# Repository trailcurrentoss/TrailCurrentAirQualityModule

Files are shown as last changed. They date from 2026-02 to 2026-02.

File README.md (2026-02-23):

# TrailCurrent Air Quality Module

Air quality sensor module for monitoring environmental conditions including temperature, humidity, and air quality metrics. Part of the [TrailCurrent](https://trailcurrent.com) open-source vehicle platform.

## Hardware Overview

- **Function:** Environmental monitoring module combining temperature, humidity, and air quality sensing
- **Key Features:**
  - DHT22 temperature and humidity sensor
  - Air quality sensing capability
  - Compact design suitable for integration into larger systems
  - PlatformIO-based firmware for configuration and operation

## Hardware Requirements

### Components

- **Sensors:**
  - DHT22 temperature/humidity sensor
  - Air quality sensor module

- **Connectors:**
  - JST XH 4-pin connectors for power and signal distribution

### KiCAD Library Dependencies

This project uses the consolidated [TrailCurrentKiCADLibraries](https://github.com/trailcurrentoss/TrailCurrentKiCADLibraries).

**Setup:**

```bash
# Clone the library
git clone git@github.com:trailcurrentoss/TrailCurrentKiCADLibraries.git

# Set environment variables (add to ~/.bashrc or ~/.zshrc)
export TRAILCURRENT_SYMBOL_DIR="/path/to/TrailCurrentKiCADLibraries/symbols"
export TRAILCURRENT_FOOTPRINT_DIR="/path/to/TrailCurrentKiCADLibraries/footprints"
export TRAILCURRENT_3DMODEL_DIR="/path/to/TrailCurrentKiCADLibraries/3d_models"
```

See [KICAD_ENVIRONMENT_SETUP.md](https://github.com/trailcurrentoss/TrailCurrentKiCADLibraries/blob/main/KICAD_ENVIRONMENT_SETUP.md) in the library repository for detailed setup instructions.

## Opening the Project

1. **Set up environment variables** (see Library Dependencies above)
2. **Open KiCAD:**
   ```bash
   kicad /path/to/EDA/TrailCurrentAirQualityModule/TrailCurrentAirQualityModule.kicad_pro
   ```
3. **Verify libraries load** - All symbol and footprint libraries should resolve without errors
4. **View 3D models** - Open PCB and press `Alt+3` to view the 3D visualization
   - All 3D models should load from the consolidated library path
   - Models use relative `${TRAILCURRENT_3DMODEL_DIR}` references

## Firmware

See `src/` directory for PlatformIO-based firmware.

**Setup:**
```bash
# Install PlatformIO (if not already installed)
pip install platformio

# Build firmware
pio run -d /path/to/project

# Upload to board
pio run -t upload -d /path/to/project
```

### Firmware Dependencies

This firmware depends on the following public libraries:

- **[C6SuperMiniRgbLedLibrary](https://github.com/trailcurrentoss/C6SuperMiniRgbLedLibrary)** (v0.0.1) - RGB LED status indicator driver
- **[Esp32C6OtaUpdateLibrary](https://github.com/trailcurrentoss/Esp32C6OtaUpdateLibrary)** (v0.0.1) - Over-the-air firmware update functionality
- **[Esp32C6TwaiTaskBasedLibrary](https://github.com/trailcurrentoss/Esp32C6TwaiTaskBasedLibrary)** (v0.0.3) - CAN bus communication interface
- **[Adafruit DHT sensor library](https://github.com/adafruit/DHT-sensor-library)** (v1.4.6+) - Temperature and humidity sensor

All dependencies are automatically resolved by PlatformIO during the build process.

**WiFi Credentials:**
- Firmware receives WiFi credentials via CAN Bus (ID 0x01) from the TrailCurrent system
- For standalone development/testing without the TrailCurrent system, create a `secrets.h` file in `src/`:
  ```cpp
  // Copy to src/secrets.h for local development only
  // NEVER commit this file - it's in .gitignore
  const char* ssid = "YOUR_SSID_HERE";
  const char* password = "YOUR_PASSWORD_HERE";
  ```

**Future Enhancement:** WiFi credential configuration will be fully implemented via CAN Bus protocol, allowing credentials to be distributed from the TrailCurrent system without firmware modifications.

## Manufacturing

- **PCB Files:** Ready for fabrication via standard PCB services (JLCPCB, OSH Park, etc.)
- **BOM Generation:** Export BOM from KiCAD schematic (Tools → Generate BOM)
- **JLCPCB Assembly:** This project supports automated assembly using JLCPCB
  - See [BOM_ASSEMBLY_WORKFLOW.md](https://github.com/trailcurrentoss/TrailCurrentKiCADLibraries/blob/main/BOM_ASSEMBLY_WORKFLOW.md) for detailed assembly workflow
  - Component library includes LCSC, Mouser, and DigiKey part numbers for flexible sourcing

## Documentation

- **Schematic:** EDA/TrailCurrentAirQualityModule/TrailCurrentAirQualityModule.kicad_sch
- **PCB Layout:** EDA/TrailCurrentAirQualityModule/TrailCurrentAirQualityModule.kicad_pcb

## License

MIT License - See LICENSE file for details

This is open source hardware. You are free to use, modify, and distribute these designs for personal or commercial purposes.

## Contributing

Improvements and contributions are welcome! Please submit issues or pull requests to the main repository.

## Support

For questions about:
- **KiCAD setup:** See [KICAD_ENVIRONMENT_SETUP.md](https://github.com/trailcurrentoss/TrailCurrentKiCADLibraries/blob/main/KICAD_ENVIRONMENT_SETUP.md)
- **Library consolidation:** See [CONNECTOR_CONSOLIDATION_SUMMARY.md](https://github.com/trailcurrentoss/TrailCurrentKiCADLibraries/blob/main/CONNECTOR_CONSOLIDATION_SUMMARY.md)
- **Assembly workflow:** See [BOM_ASSEMBLY_WORKFLOW.md](https://github.com/trailcurrentoss/TrailCurrentKiCADLibraries/blob/main/BOM_ASSEMBLY_WORKFLOW.md)

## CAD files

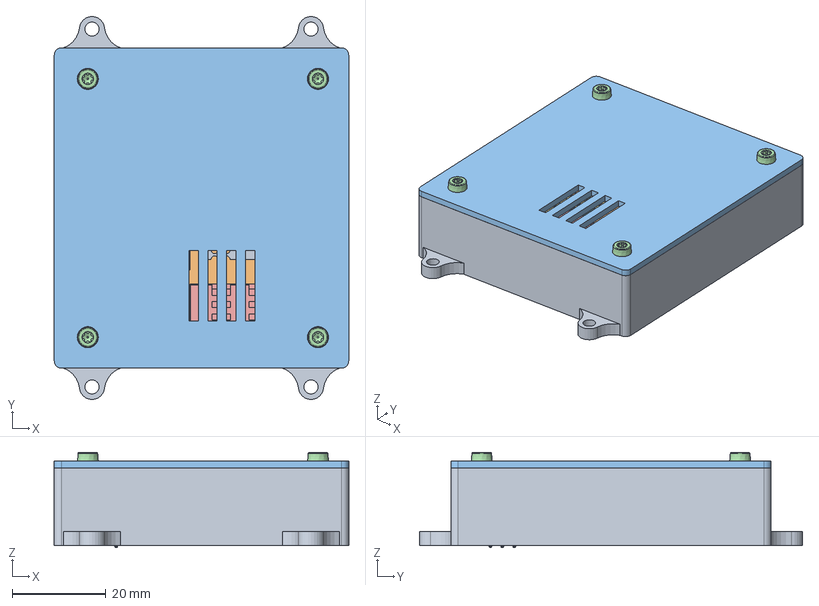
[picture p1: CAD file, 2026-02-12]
CAD/TrailCurrentAirQualityModule.FCStd
62.7 x 81.5 x 20.3 mm
BodyCaseBack
Right angle 3 pin header v1
Right angle 3 pin header v001
Right angle 3 pin header v002
dht22
PCB
USB_C_Receptacle_16P_TopMnt_Horizontal_GCT_USB4105-xx-A037
USB_C_Receptacle_16P_TopMnt_Horizontal_GCT_USB4105-xx-A038
USB_C_Receptacle_16P_TopMnt_Horizontal_GCT_USB4105-xx-A039
USB_C_Receptacle_16P_TopMnt_Horizontal_GCT_USB4105-xx-A040
USB_C_Receptacle_16P_TopMnt_Horizontal_GCT_USB4105-xx-A041
USB_C_Receptacle_16P_TopMnt_Horizontal_GCT_USB4105-xx-A042
USB_C_Receptacle_16P_TopMnt_Horizontal_GCT_USB4105-xx-A043
USB_C_Receptacle_16P_TopMnt_Horizontal_GCT_USB4105-xx-A044
USB_C_Receptacle_16P_TopMnt_Horizontal_GCT_USB4105-xx-A045
USB_C_Receptacle_16P_TopMnt_Horizontal_GCT_USB4105-xx-A046
USB_C_Receptacle_16P_TopMnt_Horizontal_GCT_USB4105-xx-A047
USB_C_Receptacle_16P_TopMnt_Horizontal_GCT_USB4105-xx-A048
USB_C_Receptacle_16P_TopMnt_Horizontal_GCT_USB4105-xx-A049
USB_C_Receptacle_16P_TopMnt_Horizontal_GCT_USB4105-xx-A050
USB_C_Receptacle_16P_TopMnt_Horizontal_GCT_USB4105-xx-A051
USB_C_Receptacle_16P_TopMnt_Horizontal_GCT_USB4105-xx-A052
USB_C_Receptacle_16P_TopMnt_Horizontal_GCT_USB4105-xx-A053
USB_C_Receptacle_16P_TopMnt_Horizontal_GCT_USB4105-xx-A054
USB_C_Receptacle_16P_TopMnt_Horizontal_GCT_USB4105-xx-A055
USB_C_Receptacle_16P_TopMnt_Horizontal_GCT_USB4105-xx-A056
USB_C_Receptacle_16P_TopMnt_Horizontal_GCT_USB4105-xx-A057
USB_C_Receptacle_16P_TopMnt_Horizontal_GCT_USB4105-xx-A058
USB_C_Receptacle_16P_TopMnt_Horizontal_GCT_USB4105-xx-A059
USB_C_Receptacle_16P_TopMnt_Horizontal_GCT_USB4105-xx-A060
USB_C_Receptacle_16P_TopMnt_Horizontal_GCT_USB4105-xx-A061
USB_C_Receptacle_16P_TopMnt_Horizontal_GCT_USB4105-xx-A062
USB_C_Receptacle_16P_TopMnt_Horizontal_GCT_USB4105-xx-A063
USB_C_Receptacle_16P_TopMnt_Horizontal_GCT_USB4105-xx-A064
USB_C_Receptacle_16P_TopMnt_Horizontal_GCT_USB4105-xx-A065
USB_C_Receptacle_16P_TopMnt_Horizontal_GCT_USB4105-xx-A066
USB_C_Receptacle_16P_TopMnt_Horizontal_GCT_USB4105-xx-A067
USB_C_Receptacle_16P_TopMnt_Horizontal_GCT_USB4105-xx-A068
USB_C_Receptacle_16P_TopMnt_Horizontal_GCT_USB4105-xx-A069
USB_C_Receptacle_16P_TopMnt_Horizontal_GCT_USB4105-xx-A070
USB_C_Receptacle_16P_TopMnt_Horizontal_GCT_USB4105-xx-A071
USB_C_Receptacle_16P_TopMnt_Horizontal_GCT_USB4105-xx-A072
Button_black_002
Button_black_003
io23
io21
io22
io12
io13
Corps
Corps001
Corps002
Corps003
Corps004
Corps005
Corps006
Corps007
Corps008
Corps009
Corps010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

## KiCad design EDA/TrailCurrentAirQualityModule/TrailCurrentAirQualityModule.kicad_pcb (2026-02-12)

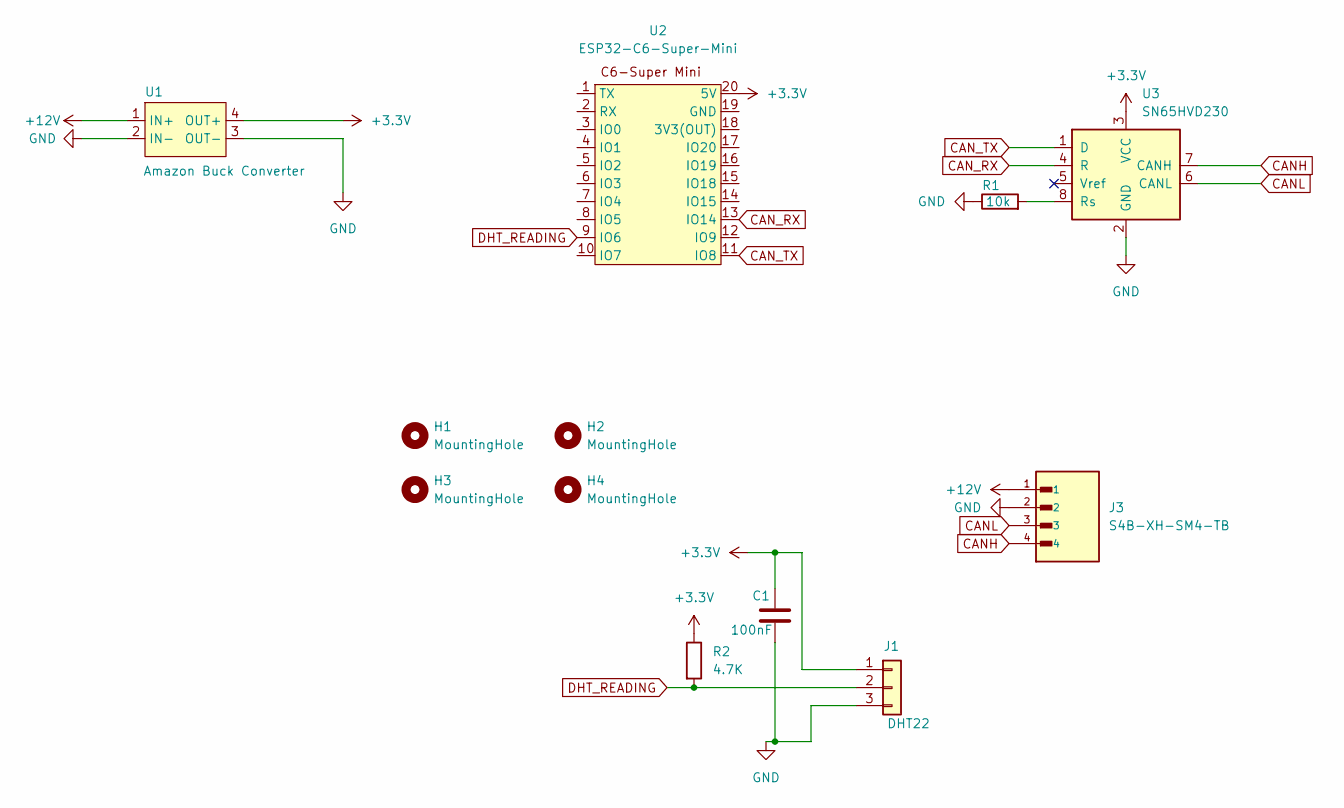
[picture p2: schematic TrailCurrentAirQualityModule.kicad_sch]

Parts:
C1: 100nF; C_1206_3216Metric_Pad1.33x1.80mm_HandSolder
H1, H2, H3, H4: MountingHole; MountingHole_2.5mm
J1: DHT22; DHT22_Module
J3: S4B-XH-SM4-TB; JST_S4B-XH-SM4-TB; PARTREV NA; LCSC C161861
R1: 10k; R_1206_3216Metric_Pad1.30x1.75mm_HandSolder
R2: 4.7K; C_1206_3216Metric_Pad1.33x1.80mm_HandSolder
U1: Amazon Buck Converter; AmazonBuckConverter
U2: ESP32-C6-Super-Mini
U3: SN65HVD230; SOIC-8_3.9x4.9mm_P1.27mm

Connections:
+3.3V: C1.1, J1.1, R2.1, U1.4 (OUT+), U2.20 (5V), U3.3 (VCC)
+12V: J3.1, U1.1 (IN+)
CANH: J3.4, U3.7 (CANH)
CANL: J3.3, U3.6 (CANL)
CAN_RX: U2.13 (IO14), U3.4 (R)
CAN_TX: U2.11 (IO8), U3.1 (D)
DHT_READING: J1.2, R2.2, U2.9 (IO6)
GND: C1.2, J1.3, J3.2, R1.1, U1.2 (IN-), U1.3 (OUT-), U3.2 (GND)
unnamed: R1.2, U3.8 (Rs)

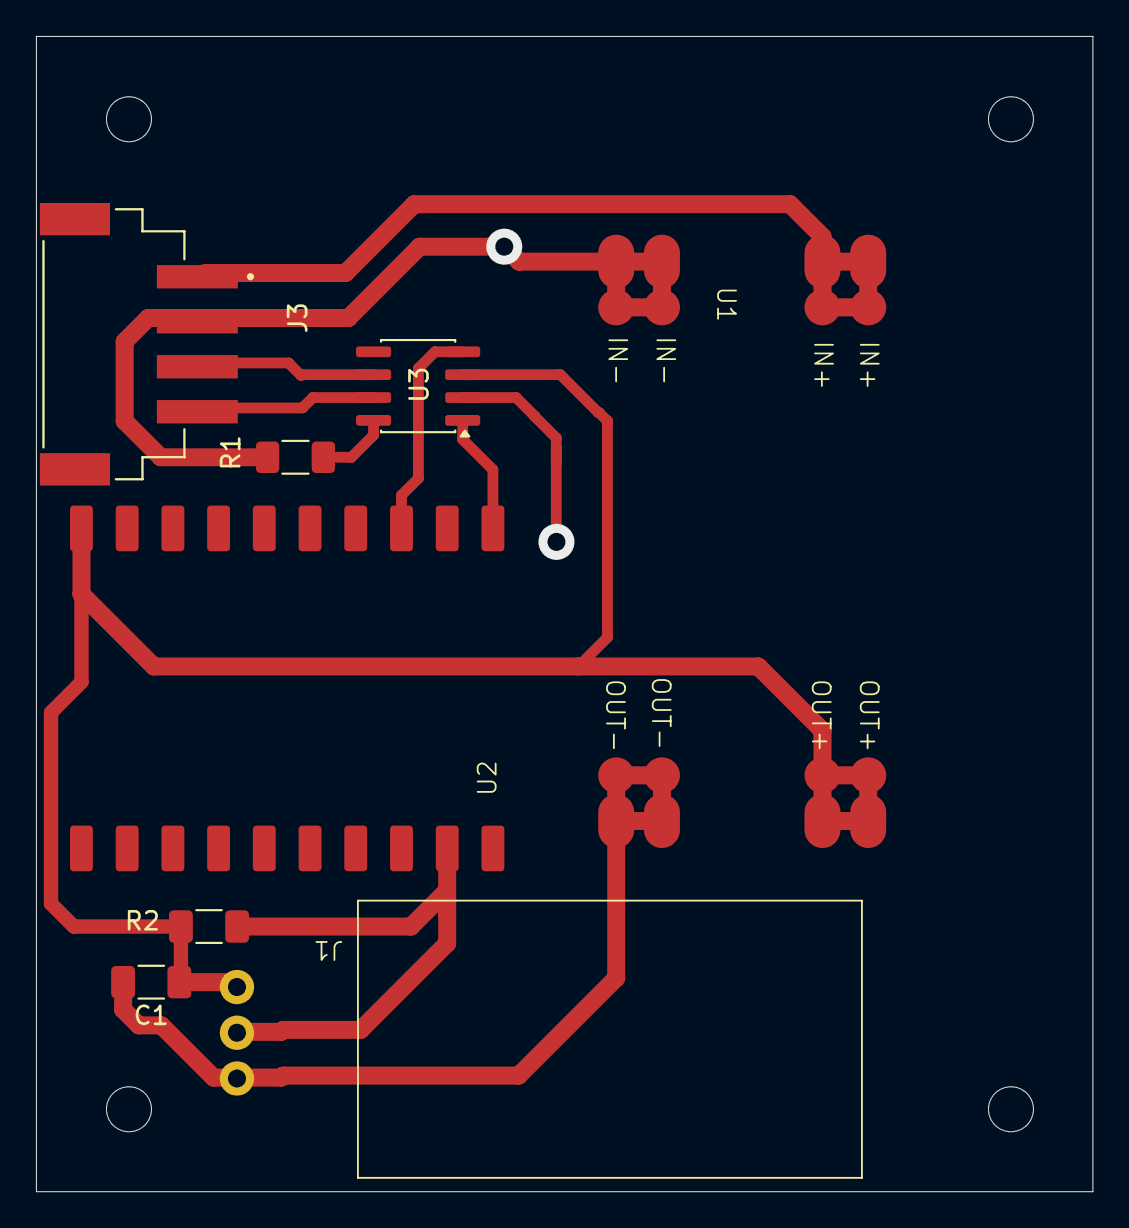
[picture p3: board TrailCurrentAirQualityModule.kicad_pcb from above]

Board: 2 copper layers, 58.7 x 64.2 mm, 12 parts (0 on the bottom side), 9 nets.

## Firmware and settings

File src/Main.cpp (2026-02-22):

#include "Dht22Sensor.h"
#include "OtaUpdate.h"
#include "RgbLed.h"
#include <Preferences.h>
#include "TwaiTaskBased.h"
#include "Globals.h"
#include <Arduino.h>
#include <driver/gpio.h>

RgbLed statusLed(8);
OtaUpdate otaUpdate(statusLed, 180000, "", "");
Dht22Sensor dht22(6);

bool currentTxErrors = false;

// WiFi credential reception state (CAN ID 0x01 protocol)
bool wifiConfigInProgress = false;
uint8_t wifiSsidBuffer[33];       // Max 32 chars + null
uint8_t wifiPasswordBuffer[64];   // Max 63 chars + null
uint8_t wifiSsidLen = 0;          // Expected total SSID length
uint8_t wifiPasswordLen = 0;      // Expected total password length
uint8_t wifiSsidReceived = 0;     // Bytes received so far
uint8_t wifiPasswordReceived = 0;

void saveWifiCredentials(const char* ssid, const char* password) {
  Preferences prefs;
  prefs.begin("wifi", false);  // read-write
  prefs.putString("ssid", ssid);
  prefs.putString("password", password);
  prefs.end();
  debugf("[WiFi] Credentials saved to NVS (SSID: %s)\n", ssid);
}

void handleWifiConfigMessage(const twai_message_t &msg) {
  uint8_t msgType = msg.data[0];

  switch (msgType) {
    case 0x01: {  // Start message
      wifiSsidLen = msg.data[1];
      wifiPasswordLen = msg.data[2];
      wifiSsidReceived = 0;
      wifiPasswordReceived = 0;
      memset(wifiSsidBuffer, 0, sizeof(wifiSsidBuffer));
      memset(wifiPasswordBuffer, 0, sizeof(wifiPasswordBuffer));
      wifiConfigInProgress = true;
      debugf("[WiFi] Config start: SSID len=%d, Password len=%d\n", wifiSsidLen, wifiPasswordLen);
      break;
    }

    case 0x02: {  // SSID chunk
      if (!wifiConfigInProgress) break;
      uint8_t dataBytes = msg.data_length_code - 2;
      uint8_t remaining = wifiSsidLen - wifiSsidReceived;
      if (dataBytes > remaining) dataBytes = remaining;
      if (wifiSsidReceived + dataBytes <= 32) {
        memcpy(wifiSsidBuffer + wifiSsidReceived, &msg.data[2], dataBytes);
        wifiSsidReceived += dataBytes;
      }
      break;
    }

    case 0x03: {  // Password chunk
      if (!wifiConfigInProgress) break;
      uint8_t dataBytes = msg.data_length_code - 2;
      uint8_t remaining = wifiPasswordLen - wifiPasswordReceived;
      if (dataBytes > remaining) dataBytes = remaining;
      if (wifiPasswordReceived + dataBytes <= 63) {
        memcpy(wifiPasswordBuffer + wifiPasswordReceived, &msg.data[2], dataBytes);
        wifiPasswordReceived += dataBytes;
      }
      break;
    }

    case 0x04: {  // End message with checksum
      if (!wifiConfigInProgress) break;
      wifiConfigInProgress = false;

      // Verify XOR checksum
      uint8_t checksum = 0;
      for (uint8_t i = 0; i < wifiSsidReceived; i++) checksum ^= wifiSsidBuffer[i];
      for (uint8_t i = 0; i < wifiPasswordReceived; i++) checksum ^= wifiPasswordBuffer[i];

      if (checksum == msg.data[1] && wifiSsidReceived == wifiSsidLen && wifiPasswordReceived == wifiPasswordLen) {
        wifiSsidBuffer[wifiSsidReceived] = '\0';
        wifiPasswordBuffer[wifiPasswordReceived] = '\0';
        saveWifiCredentials((const char*)wifiSsidBuffer, (const char*)wifiPasswordBuffer);
      } else {
        debugf("[WiFi] Config failed: checksum %s, SSID %d/%d bytes, Password %d/%d bytes\n",
               (checksum == msg.data[1]) ? "OK" : "MISMATCH",
               wifiSsidReceived, wifiSsidLen, wifiPasswordReceived, wifiPasswordLen);
      }
      break;
    }
  }
}

void onCanRx(const twai_message_t &msg) {
  if (msg.identifier == 0) {
    Serial.println("Got message for someone to update");
    char updateForHostName[14];
    String currentHostName = otaUpdate.getHostName();
    sprintf(updateForHostName, "esp32c6-%X%X%X", msg.data[0], msg.data[1],
            msg.data[2]);
    Serial.println(updateForHostName);
    if (currentHostName.equals(updateForHostName)) {
      debugln("[OTA] Hostname matched - reading WiFi credentials from NVS");
      Preferences prefs;
      prefs.begin("wifi", true);  // read-only
      String ssid = prefs.getString("ssid", "");
      String password = prefs.getString("password", "");
      prefs.end();

      if (ssid.length() > 0 && password.length() > 0) {
        debugf("[OTA] Using stored WiFi credentials (SSID: %s)\n", ssid.c_str());
        OtaUpdate ota(statusLed, 180000, ssid.c_str(), password.c_str());
        ota.waitForOta();
        debugln("[OTA] OTA mode exited - resuming normal operation");
      } else {
        debugln("[OTA] ERROR: No WiFi credentials in NVS - cannot start OTA");
      }
    }
  }
  else if (msg.identifier == 0x01) {
    handleWifiConfigMessage(msg);
  }
}

void onCanTx(bool ok) {
  currentTxErrors = !ok;
  debugln(ok ? "TX OK" : "TX FAIL");
}

void setup() {
  Serial.begin(115200);
#if DEBUG == 0
  Serial.println(
      "Debugging is disabled no more output will be written here...");
#else
  Serial.println("Debugging started");
#endif
  statusLed.begin();
  statusLed.setBrightnessPercent(1);
  TwaiTaskBased::onReceive(onCanRx);
  TwaiTaskBased::onTransmit(onCanTx);
  TwaiTaskBased::begin(GPIO_NUM_15, GPIO_NUM_14, 500000);
  dht22.begin();
  statusLed.green();
  debugln("Setup done");
}

void loop() {
  dht22.readAndSend();
}

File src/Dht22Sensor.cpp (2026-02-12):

#include "Dht22Sensor.h"
#include "Globals.h"
#include "TwaiTaskBased.h"

#include <Adafruit_Sensor.h>
#include <DHT_U.h>

#define DHTTYPE DHT22

Dht22Sensor::Dht22Sensor(uint8_t pin)
  : _dht(pin, DHTTYPE) {}

void Dht22Sensor::begin() {
  _dht.begin();
}

void Dht22Sensor::readAndSend() {
  float humidity = _dht.readHumidity();
  float temperatureC = _dht.readTemperature();

  if (isnan(humidity) || isnan(temperatureC)) {
    debugln("Failed to read from DHT22 sensor");
    return;
  }

  Serial.print("Humidity: ");
  Serial.print(humidity);
  Serial.print(" %, Temp: ");
  Serial.print(temperatureC);
  Serial.println(" Celsius");

  sendTwaiMessage(temperatureC, humidity);

  delay(1000); // DHT22 minimum read interval
}

void Dht22Sensor::sendTwaiMessage(float temperatureC, float humidity) {
  uint16_t humidityScaled = static_cast<uint16_t>(humidity * 100.0f);
  uint8_t humidityWhole = (humidityScaled >> 8) & 0xFF;
  uint8_t humidityDecimal = humidityScaled & 0xFF;

  int temperatureCInt = static_cast<int>(temperatureC);
  int temperatureFInt = ((temperatureCInt * 9) + 3) / 5 + 32;

  debugln(temperatureFInt);

  twai_message_t msg = {};
  msg.identifier = 0x01F;
  msg.data_length_code = 4;
  msg.data[0] = temperatureCInt;
  msg.data[1] = temperatureFInt;
  msg.data[2] = humidityWhole;
  msg.data[3] = humidityDecimal;

  TwaiTaskBased::send(msg);
}

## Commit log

2026-02-12 Initial commit: Clean migration to public Codeberg repository
    This is a fresh start on Codeberg with all security and configuration
    issues addressed:
    Security fixes:
    - Removed all git history (fresh start)
    - No personal paths or credentials exposed
    - All WiFi secrets in .gitignore (using secrets.h.example pattern)
    - Private keys protected
    - Internal URLs replaced with public Codeberg references
    Configuration updates:
    - Updated all GitHub references to Codeberg
    - KiCAD projects use environment variables for library paths
    - Platform IO dependencies point to public repositories
    - All .gitignore files comprehensive
    Ready for public use.
    [TrailCurrentAirQualityModule.FCStd, TrailCurrentAirQualityModule.kicad_pcb, TrailCurrentAirQualityModule.kicad_sch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]
2026-02-22 Updated to remove secrets and get them from CAD
